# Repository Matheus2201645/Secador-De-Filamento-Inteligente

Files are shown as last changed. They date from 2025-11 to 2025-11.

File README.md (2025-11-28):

Desenvolvido por Matheus Milani, Thiago moraes, Kassem hamdoun, Vinicius Rodriges
Alunos instituto maua de tecnologia
Projeto ECA407 e ECA409

  Funcionalidades

Leitura de temperatura e umidade (SHT31)

Leitura de peso via HX711 + célula de carga

Controle automático:

Aquecedor (GPIO22)

Ventoinha (GPIO20)

Comunicação via USB Serial

Dashboard em PySide6 para monitoramento em tempo real

  Arquivos do Projeto

SecadoraInteligenteFinal.c – Firmware do Pico (leitura dos sensores, controle e envio serial)

Ui.py – Dashboard PySide6

CMakeLists.txt – Configuração do projeto

   Instalar Dashboard
pip install pyserial PySide6
python Ui.py

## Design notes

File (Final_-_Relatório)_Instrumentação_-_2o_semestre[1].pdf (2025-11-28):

SECADOR INTELIGENTE DE FILAMENTOS PARA IMPRESSÃO 3D

Matheus Milani 1

; Thiago Moraes 1

; Kassem Hamdoun 1

; Vinicius Rodrigues 1

1 Aluno do Instituto Mauá de Tecnologia (IMT).

Resumo. Este relatório apresenta o desenvolvimento de um secador inteligente de filamentos para impressão 3D, capaz de realizar simultaneamente o controle térmico para remoção de umidade e a medição precisa do peso do filamento restante. O sistema integra sensores, atuadores, uma placa controladora personalizada e um servidor web embarcado no Raspberry Pi Pico 2W, permitindo monitoramento e acionamento remoto do dispositivo. A solução proposta visa reduzir desperdícios, evitar falhas de impressão e melhorar a qualidade das peças produzidas em impressoras 3D do tipo FDM.

Introdução

A impressão 3D tornou-se uma tecnologia amplamente utilizada em processos educacionais, industriais e de prototipagem. Contudo, um dos maiores problemas enfrentados por usuários de impressoras do tipo FDM é a umidade acumulada nos filamentos termoplásticos, que compromete a qualidade das peças, causando bolhas, fissuras e superfícies irregulares.
Outro desafio recorrente é a ausência de informações precisas sobre a quantidade de filamento restante no carretel, o que pode resultar em interrupções inesperadas durante o processo de impressão, gerando desperdício de tempo, energia e material.
Diante desse cenário, este projeto propõe o desenvolvimento de um secador inteligente de filamentos com medição integrada de peso e controle remoto via servidor HTTP, oferecendo uma solução prática e eficaz para usuários de impressão 3D.
O presente projeto tem como objetivo desenvolver um dispositivo capaz de:
-) Secar filamentos de impressão 3D por meio de controle térmico;
-) Medir, em tempo real, o peso do filamento restante no carretel;
-) Disponibilizar uma interface web acessível via Wi-Fi, permitindo monitoramento e acionamento remoto do sistema;
-) Reduzir desperdícios e falhas decorrentes da umidade ou falta de filamento;
-) Unificar automação, eletrônica e software em uma solução compacta e acessível.

Material e Métodos

Materiais utilizados:

Os materiais utilizados no projeto foram: -) Raspberry Pi Pico 2W;
-) Módulo HX711;
-) Load Cell;
-) Sensor de temperatura SHT31;
-) Lâmpada aquecedora de réptil (100 W); -) Relé de estado sólido;
-) Coolers 5V (2 unidades);
-) Transistores BC547 (3 unidades);
-) Resistores de 1 kΩ (3 unidades);
-) Fonte de alimentação 5 V;
-) PCB personalizada (placa de circuito); -) Estrutura física impressa em 3D;
-) Conector C14.

Fundamentação teórica

Quanto à impressão 3D e efeitos da umidade, filamentos termoplásticos como PLA, ABS, PETG e Nylon são higroscópicos, absorvendo umidade naturalmente. Quando aquecidos no bico da impressora, o vapor de água interno gera estalos, bolhas e inconsistências estruturais.
Por isso, técnicas de secagem são essenciais para restaurar características ideais de impressão.
A load cell é um sensor baseado em extensômetros que converte força em deformação mecânica, permitindo medir massa. O módulo HX711 realiza a amplificação e conversão analógica-digital do sinal, possibilitando leitura precisa pelo microcontrolador.
O controle da temperatura é realizado por meio de um sensor digital (SHT31), que monitora o ambiente interno do secador e fornece dados para os atuadores (aquecedor e ventilação).
O Pico 2W possui conectividade Wi-Fi integrada, permitindo a criação de servidores web. Isso possibilita monitorar variáveis do sistema e enviar comandos para atuadores via navegador.

Descrição do projeto

O presente projeto consiste no desenvolvimento de um secador inteligente de filamentos para impressoras 3D, cuja finalidade é remover a umidade acumulada no material e fornecer ao usuário informações em tempo real sobre o peso restante do filamento. O sistema integra eletrônica, automação, controle térmico e interface web em um dispositivo compacto e eficiente.
O projeto é estruturado em três módulos principais:

Módulo Eletrônico de Controle:

O módulo eletrônico é composto por uma placa de circuito impresso (PCB) desenvolvida especificamente para o projeto, na qual estão integrados o microcontrolador Raspberry Pi Pico 2W, o módulo amplificador HX711, transistores, resistores de proteção e conexões para o relé de estado sólido e ventiladores.
Esse módulo realiza:
-) a leitura do sinal da célula de carga;
-) o monitoramento da temperatura interna através do sensor SHT31;
-) o acionamento dos atuadores (coolers e aquecedor);
-) a disponibilização dos dados coletados em uma interface web via Wi‑Fi.

Módulo Térmico e de Circulação de Ar:

A secagem do filamento ocorre por meio de uma lâmpada aquecedora de 100 W, acionada por um relé de estado sólido (SSR), que garante comutação rápida e segura.
A circulação de ar quente é realizada por dois coolers de 5 V, responsáveis por distribuir uniformemente o calor dentro da câmara de secagem.
O sensor SHT31, instalado próximo ao fluxo de ar, monitora continuamente a temperatura, garantindo segurança térmica e eficiência no processo.

Estrutura Mecânica:

A estrutura externa e os suportes internos foram projetados em ambiente CAD e produzidos por impressão 3D. A carcaça acomoda o rolo de filamento, a célula de carga e todos os módulos eletrônicos, além de fornecer:
-) estabilidade mecânica;
-) isolamento térmico adequado;

-) compartimentação dos elementos funcionais; -) facilidade de montagem e manutenção.
-) O conjunto permite ao usuário:
-) secar filamentos de maneira controlada;
-) monitorar temperatura e peso pelo navegador;
-) reduzir falhas de impressão relacionadas à umidade;
-) prevenir interrupções inesperadas devido à falta de material.

Metodologia

A construção do secador inteligente foi realizada em etapas simples e organizadas, passando pelo planejamento da arquitetura, montagem eletrônica, desenvolvimento da estrutura mecânica e integração final.

Arquitetura Geral do Sistema:

Primeiro, definimos como cada parte do projeto deveria se comunicar — sensores, atuadores e o Raspberry Pi Pico 2W. Para facilitar a visualização, elaboramos um diagrama de blocos, como mostrado na Figura 1.

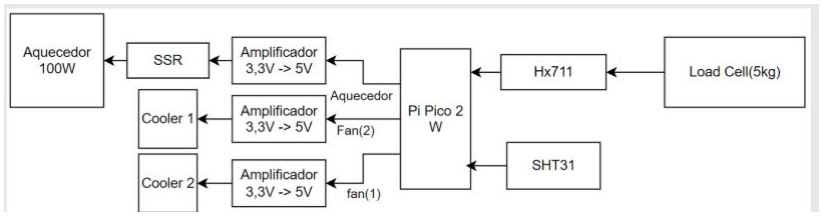
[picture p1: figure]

Figura 1 – Diagrama de blocos do projeto. Fonte: Autoria própria (2025).

Alimentação do Sistema:

Escolhemos uma fonte chaveada de 5 V para alimentar todos os componentes, como mostrado na Figura 2. Ela garante estabilidade e segurança durante o funcionamento.

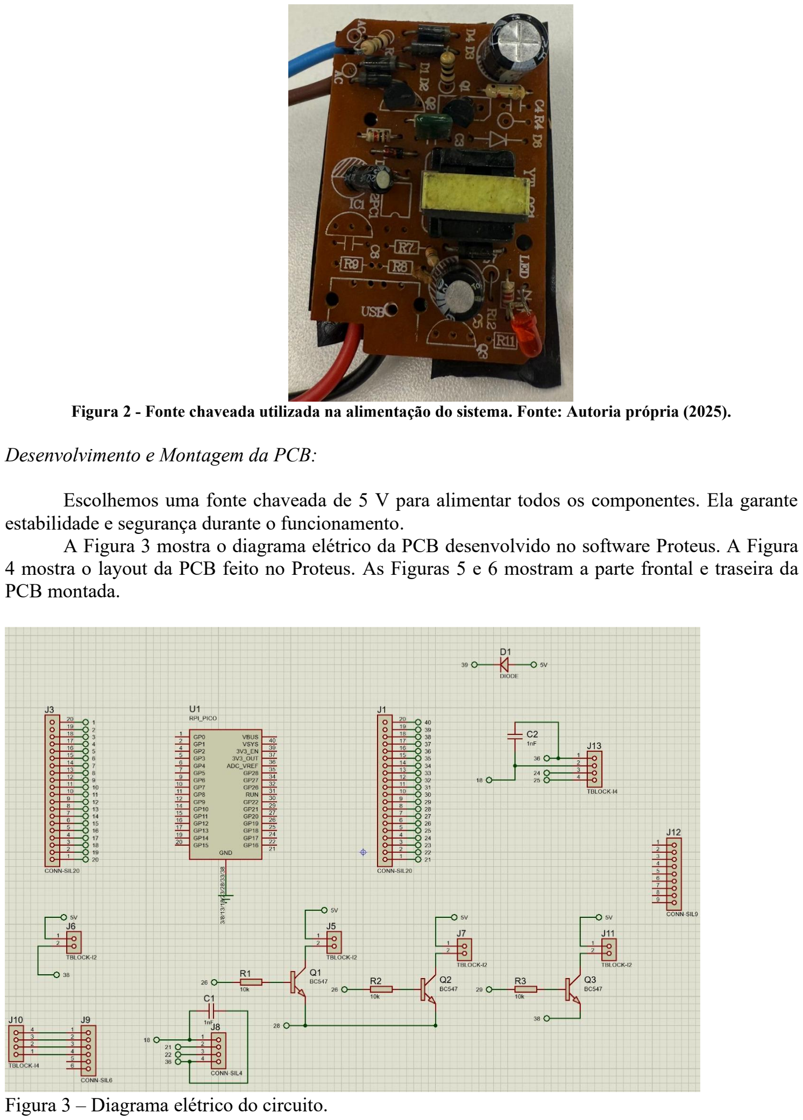
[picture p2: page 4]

Figura 2 - Fonte chaveada utilizada na alimentação do sistema. Fonte: Autoria própria (2025).

Desenvolvimento e Montagem da PCB:

Escolhemos uma fonte chaveada de 5 V para alimentar todos os componentes. Ela garante estabilidade e segurança durante o funcionamento.
A Figura 3 mostra o diagrama elétrico da PCB desenvolvido no software Proteus. A Figura 4 mostra o layout da PCB feito no Proteus. As Figuras 5 e 6 mostram a parte frontal e traseira da PCB montada.

Figura 3 – Diagrama elétrico do circuito.

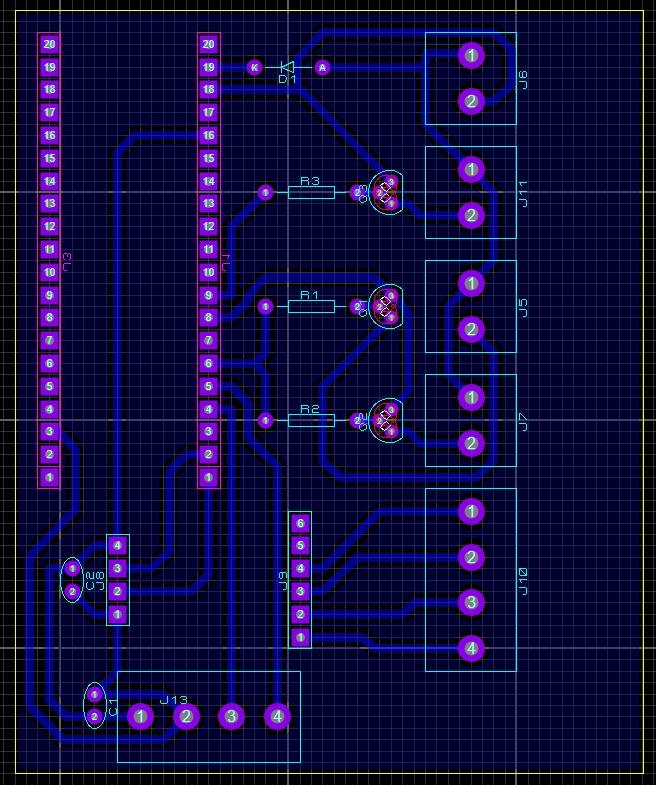
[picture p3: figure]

Figura 4 – Layout da PCB desenvolvido no Proteus.

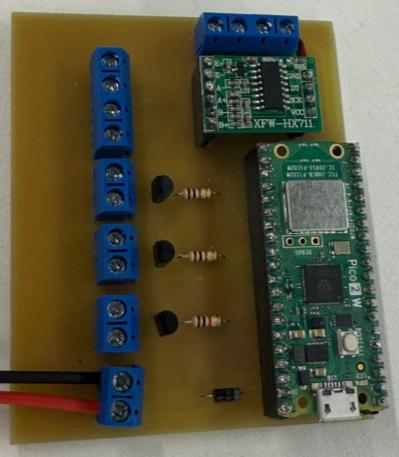
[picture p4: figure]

Figura 5 – Vista superior da PCB com Pico 2W, HX711 e transistores.

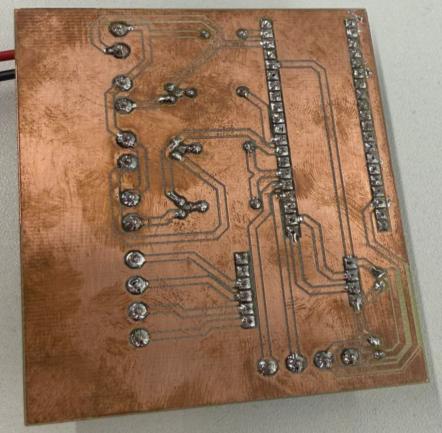
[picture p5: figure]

Figura 6 - Trilhamento inferior da PCB, mostrando conexões e soldagem.

Montagem Interna do Equipamento:

Com a placa pronta, passamos a integrar todos os componentes dentro da estrutura impressa em 3D, posicionando aquecedor, coolers e cabeamento. As Figuras 5 e 6 mostram a montagem do equipamento.

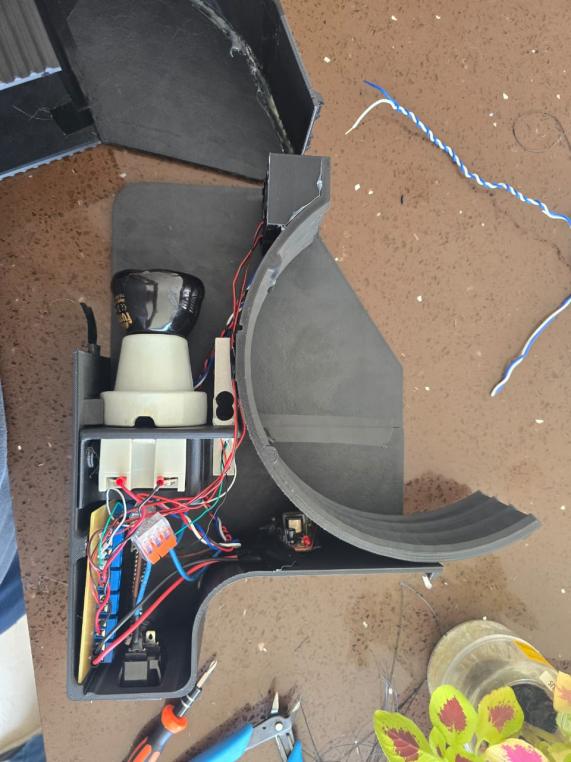
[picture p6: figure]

Figura 7 - Montagem interna com aquecedor, coolers e fiações.

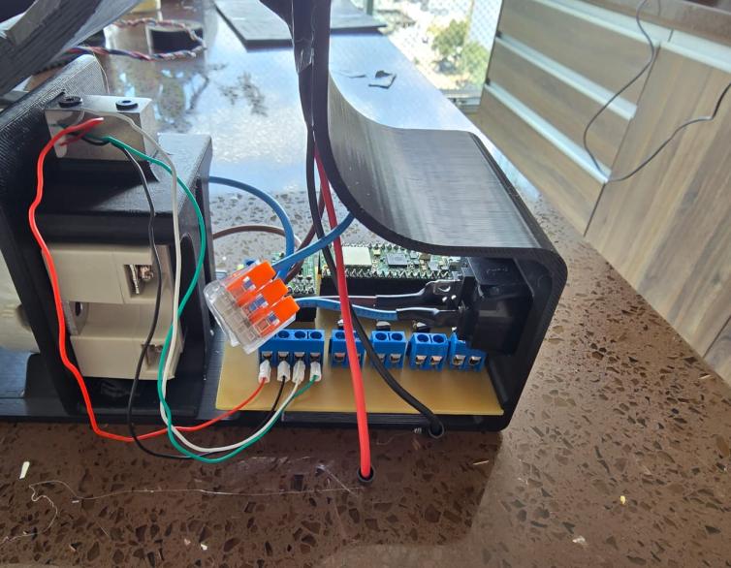
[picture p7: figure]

Figura 8 - PCB instalada no compartilhamento da estrutura.

Estrutura Mecânica Impressa em 3D.:

A estrutura foi modelada em CAD (Figura 7 e 8) e impressa em 3D, garantindo encaixe adequado dos componentes e boa circulação de ar.

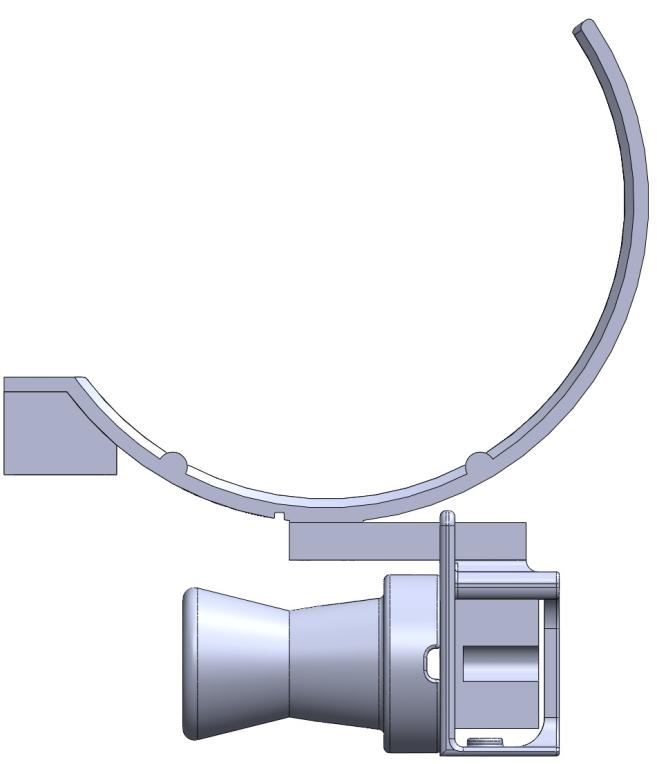
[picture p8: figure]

Figura 9 - Vista lateral do modelo 3D da estrutura.

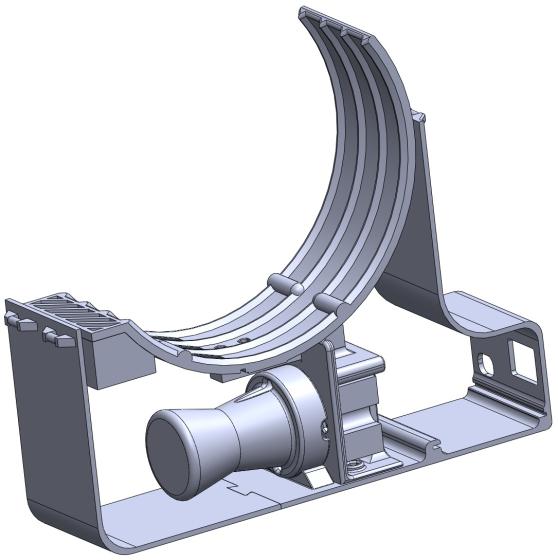
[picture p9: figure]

Figura 10 - Vista isométrica do modelo 3D.

Software do Sistema (Firmware e Interface de Monitoramento)

O software desenvolvido para o projeto é composto por duas partes principais:
(1) o firmware embarcado no Raspberry Pi Pico 2W, responsável pela leitura dos sensores e controle dos atuadores; e
(2) uma interface gráfica de monitoramento, criada em Python com PySide6, que permite visualizar em tempo real os dados transmitidos pela porta serial.

Firmware embarcado:

O firmware implementado no Raspberry Pi Pico 2W realiza a leitura dos sensores de temperatura/umidade (SHT31) e peso (HX711), além do controle automático do aquecedor e da ventoinha presentes no sistema de secagem de filamentos.

Na etapa de inicialização, o programa configura os pinos GPIO utilizados pelo HX711, pelo SHT31 (via I²C), pelo relé de estado sólido responsável pelo acionamento do aquecedor e pela ventoinha. O firmware também inicializa a comunicação I²C e executa um processo de tara da balança, realizando diversas leituras consecutivas do módulo HX711 e armazenando a média dessas leituras como ZERO_OFFSET, o que garante que o valor medido posteriormente corresponda apenas ao filamento e ao carretel.
Durante a execução contínua do laço principal, o firmware realiza periodicamente a leitura da temperatura e da umidade pelo SHT31 e obtém o peso calibrado a partir da célula de carga, utilizando o fator CALIBRATION_FACTOR. Em seguida, aplica uma lógica de controle baseada em histerese: quando a temperatura fica abaixo de 80 °C, o aquecedor é ativado; acima de 85 °C, é desativado. Caso o sistema ultrapasse o limite de segurança de 95 °C, o aquecedor é imediatamente desligado, e uma mensagem de alerta é exibida no console.
A ventoinha é acionada automaticamente sempre que a temperatura ultrapassa 35 °C ou enquanto o aquecedor estiver ligado, garantindo circulação do ar quente no interior da câmara. Ao final de cada ciclo, o firmware registra no terminal, via porta serial, os valores de temperatura, umidade, peso e estado do aquecedor, possibilitando o monitoramento em tempo real.

Interface gráfica de monitoramento (PySide6):

Para complementar o funcionamento do firmware, foi desenvolvida uma interface gráfica utilizando Python e PySide6, permitindo que os dados enviados pelo Raspberry Pi Pico 2W sejam exibidos de forma visual, organizada e acessível. A interface se conecta à porta serial selecionada pelo usuário e interpreta, linha a linha, as mensagens transmitidas pelo firmware.

Cada linha contém informações no formato:

T: xx.x C | H: xx.x % | Peso: xxxx | Aquecedor: ON/OFF

A aplicação processa esses dados e atualiza automaticamente um dashboard composto por quatro indicadores principais:
-) Temperatura (°C): exibida em destaque em um painel laranja;
-) Umidade (%): mostrada em painel azul;
-) Peso (g): exibido em painel verde;
-) Estado do aquecedor: mostrado em painel vermelho, indicando se está ON ou OFF.

Abaixo dos indicadores, a interface apresenta também um log serial contínuo, permitindo visualizar todas as mensagens recebidas do firmware em ordem cronológica. Essa interface auxilia durante testes e validações, fornecendo acompanhamento visual do comportamento térmico, da variação do peso do filamento e do acionamento dos atuadores durante o processo de secagem.
A interface gráfica é mostrada na Figura 9.

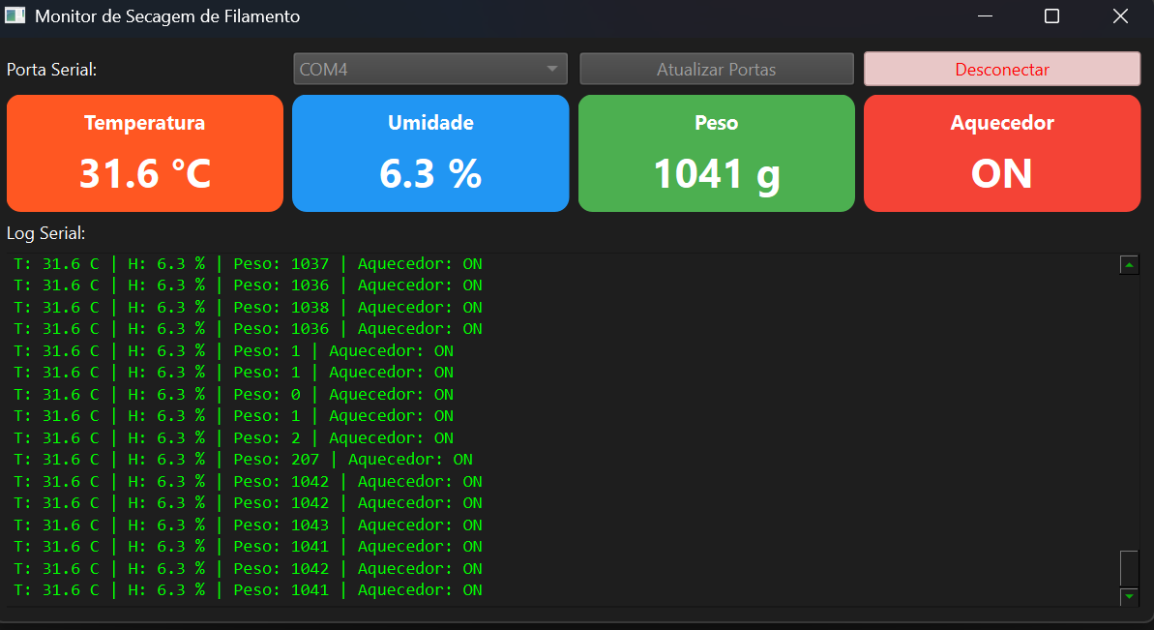
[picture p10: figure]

Figura 11 - Interface gráfica.

Resultados e Discussão

O desenvolvimento do projeto apresentou resultados funcionais, embora algumas limitações tenham sido encontradas ao longo do processo. A principal delas foi a impossibilidade de integrar a parte web ao Raspberry Pi Pico 2W. Diante disso, o grupo optou por simplificar a solução e utilizar a comunicação serial, criando uma interface em Python para permitir que o usuário acompanhasse o funcionamento do sistema diretamente pelo computador. Essa abordagem mostrou‑se viável e prática dentro do tempo disponível.
Durante os testes, verificou‑se que o sistema é capaz de atingir temperaturas elevadas, alcançando aproximadamente 80 °C em cerca de 40 minutos. Esse desempenho indica que o equipamento possui potencial para secar adequadamente diversos tipos de filamento, inclusive materiais mais sensíveis à umidade.
A célula de carga apresentou resultados satisfatórios, com medições consistentes e variação aproximada de ±5 g, o que é adequado para monitorar o consumo de filamento durante o processo de impressão 3D. Da mesma forma, a interface gráfica desenvolvida se mostrou bastante eficiente, exibindo de forma clara informações de temperatura, umidade, peso e estado do aquecedor, facilitando o acompanhamento em tempo real.
Mesmo com as limitações encontradas — tanto na integração Wi‑Fi quanto na necessidade de simplificar algumas etapas — o sistema funcionou de forma estável e cumpriu seus objetivos principais. Assim, consideramos que o projeto foi um sucesso dentro da proposta apresentada, entregando uma solução funcional, simples e efetiva.

Conclusões

O secador inteligente de filamentos apresenta uma solução prática e eficiente para problemas comuns na impressão 3D. A integração entre hardware, software embarcado e interface web demonstra o potencial da automação aplicada a dispositivos cotidianos. O projeto cumpre os objetivos propostos e pode ser ampliado futuramente com controle PID, armazenamento de dados em nuvem e otimização estrutural.

Referências Bibliográficas

IDRYER-UNIT. Disponível em: https://github.com/pavluchenkor/iDryer-Unit. Acesso em: 15 out. 2025.
AVIA SEMICONDUCTOR. 24-Bit Analog-to-Digital Converter (ADC) for Weigh Scales.
Disponível | em: | https://cdn.sparkfun.com/datasheets/Sensors/ForceFlex/hx711_english.pdf.
Acesso em: 25 out. 2025.
SENSIRION. Datasheet | SHT3x-DIS. | Disponível | em:
https://sensirion.com/media/documents/213E6A3B/63A5A569/Datasheet_SHT3x_DIS.pdf. Acesso em: 26 out. 2025.
RASPBERRY | PI | FOUNDATION. Pico-series | Microcontrollers. | Disponível | em:
https://www.raspberrypi.com/documentation/microcontrollers/pico-series.html. Acesso em: 10 out. 2025.

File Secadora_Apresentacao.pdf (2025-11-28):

# Secadora de Filamento Inteligente

# Instrumentação + Microcontroladores

Vinícius G. Rodrigues - 22.01711-9

Matheus Milani - 22.01645-7 | Thiago C. S. Moraes - 22.01303-2

Kassem Mahmoud Hamdoun - 22.00380-0

# Introdução

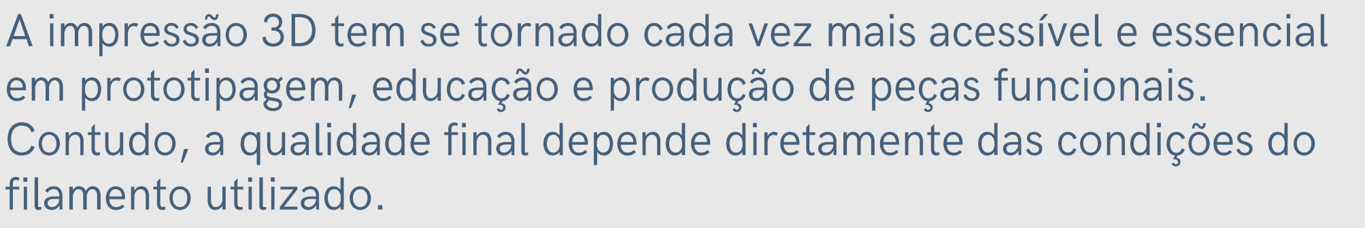
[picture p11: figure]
filamento utilizado.

- A impressão 3D tem se tornado cada vez mais acessível e essencial em prototipagem, educação e produção de peças funcionais. Contudo, a qualidade final depende diretamente das condições do

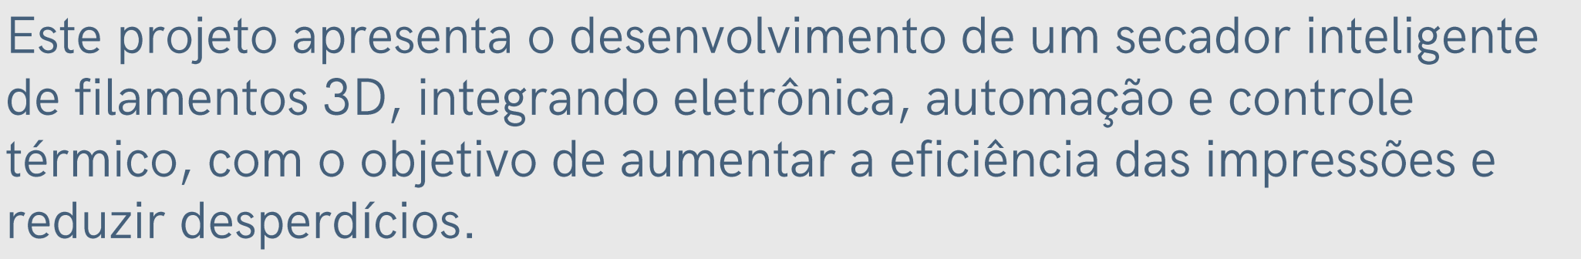
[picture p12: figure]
reduzir desperdícios.

- Este projeto apresenta o desenvolvimento de um secador inteligente de filamentos 3D, integrando eletrônica, automação e controle térmico, com o objetivo de aumentar a eficiência das impressões e

01

01.1

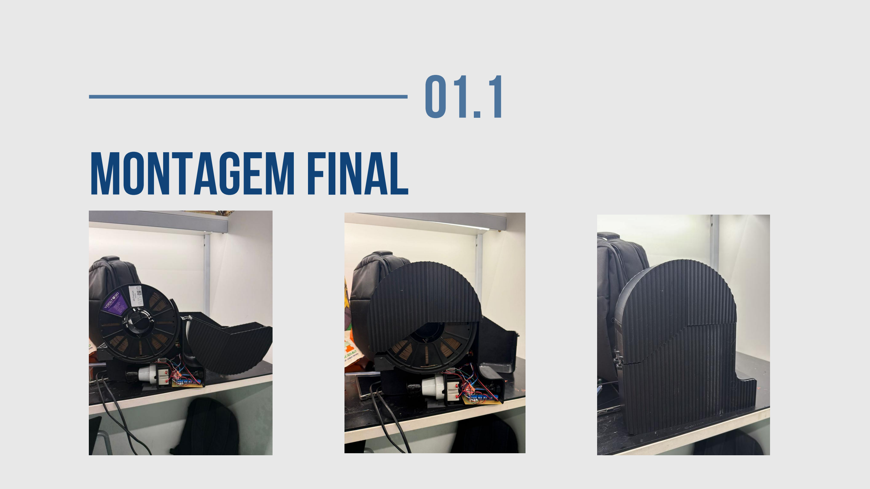
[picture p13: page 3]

# Montagem final

# Objetivo do projeto

- Desenvolver um dispositivo capaz de secar filamentos de impressão 3D, removendo umidade excessiva.

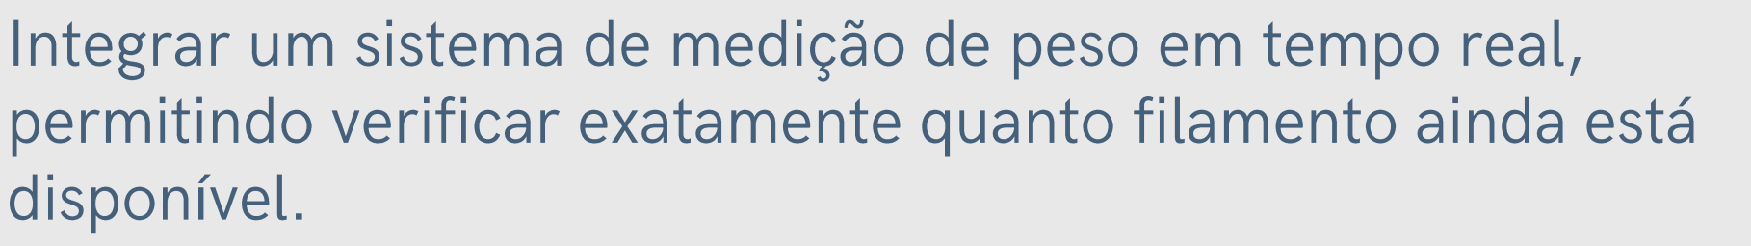
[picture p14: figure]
disponível.

- Integrar um sistema de medição de peso em tempo real, permitindo verificar exatamente quanto filamento ainda está

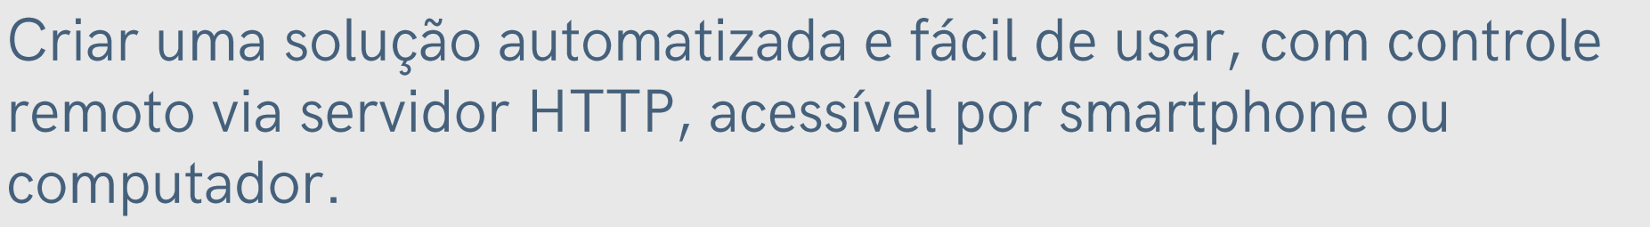
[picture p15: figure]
computador.

- Criar uma solução automatizada e fácil de usar, com controle remoto via servidor HTTP, acessível por smartphone ou
- Reduzir falhas de impressão, melhorar a qualidade final das

02

# Diagrama de blocos

03

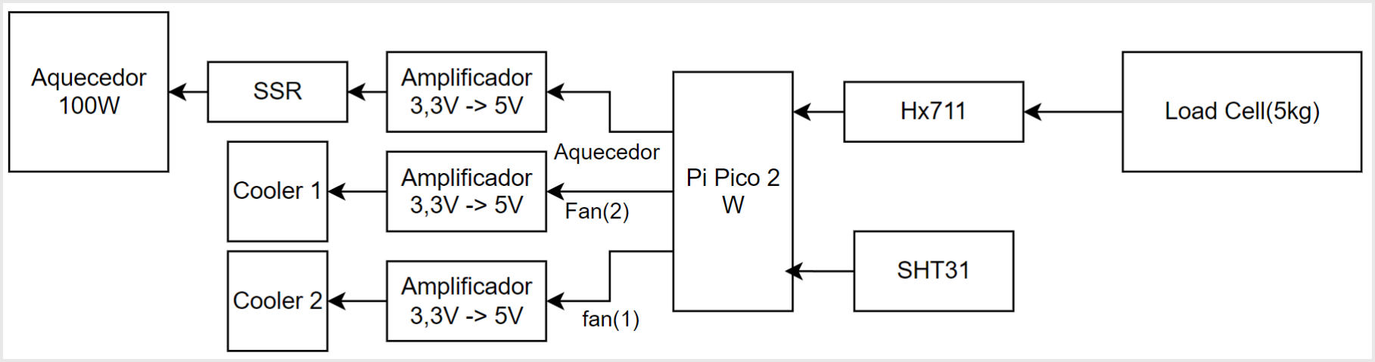
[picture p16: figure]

# Arquitetura do Sistema

03 | • Raspberry Pi Pico 2W como controlador principal
| • SHT31 para leitura de temperatura e umidade
- Load Cell + HX711 para medir o peso

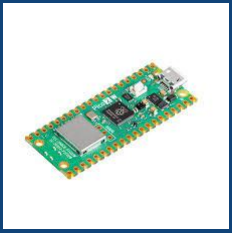
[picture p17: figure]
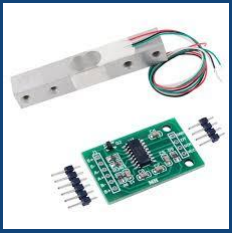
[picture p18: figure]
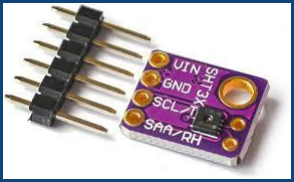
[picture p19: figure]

# Arquitetura do Sistema

03 | • Aquecedor (lâmpada de réptil 100W) com
- Coolers 5V controlados por transistores BC547
- Fonte chaveada convertendo AC → 5V DC

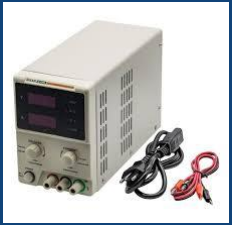
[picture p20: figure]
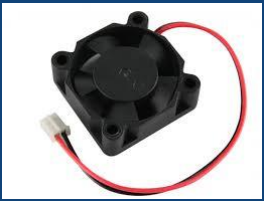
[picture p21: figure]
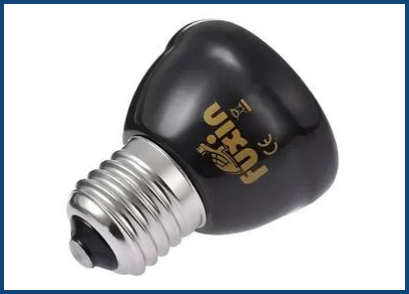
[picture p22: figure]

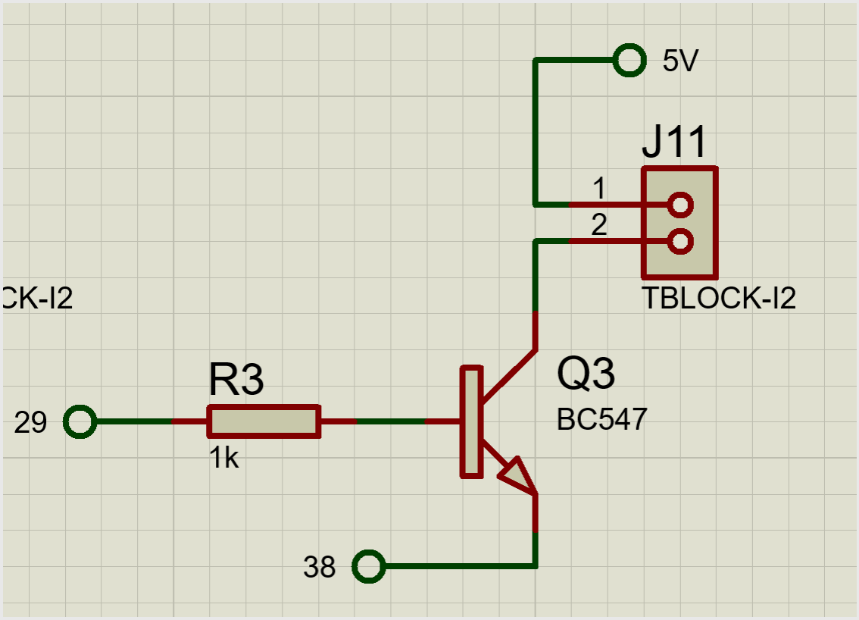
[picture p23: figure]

# Arquitetura do Sistema

03

04

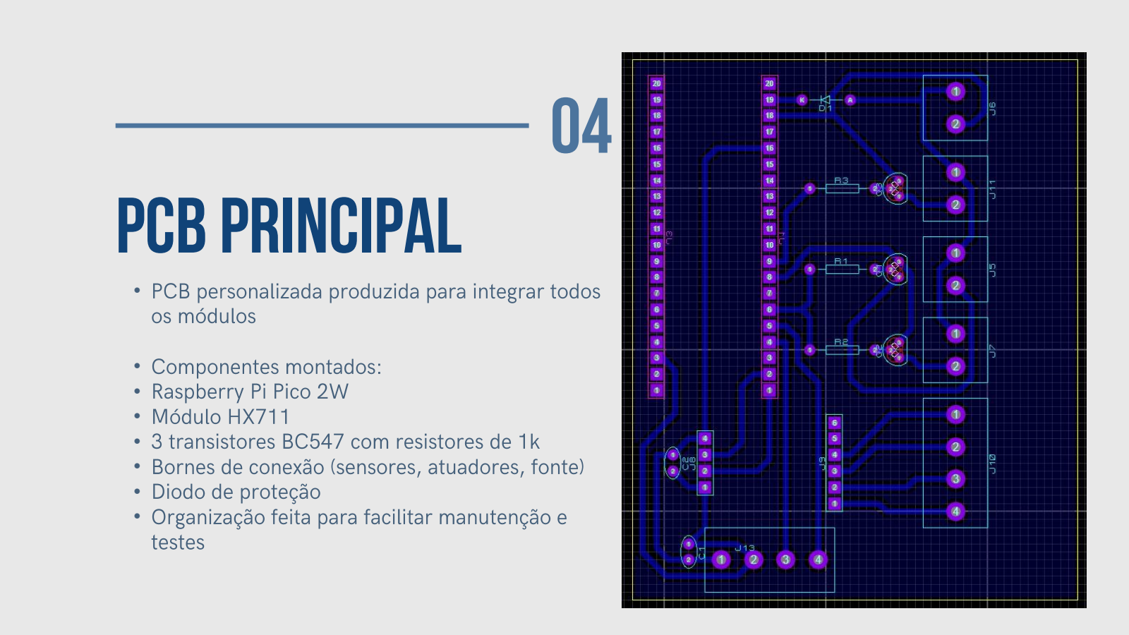
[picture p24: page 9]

# PCB Principal

- PCB personalizada produzida para integrar todos os módulos
- Componentes montados:
- Raspberry Pi Pico 2W
- Módulo HX711
- 3 transistores BC547 com resistores de 1k
- Bornes de conexão (sensores, atuadores, fonte)
- Diodo de proteção
- Organização feita para facilitar manutenção e testes

04


# PCB Principal

- PCB personalizada produzida para integrar todos os módulos
- Componentes montados:
- Raspberry Pi Pico 2W
- Módulo HX711
- 3 transistores BC547 com resistores de 1k
- Bornes de conexão (sensores, atuadores, fonte)
- Diodo de proteção
- Organização feita para facilitar manutenção e testes

# PCB (Frente / verso)

05


06


# Parte Mecânica (Suporte 3D)

- Suporte do carretel impresso em 3D
- Estrutura curvada para distribuição do peso
- Base encaixada diretamente na load cell
- Mantém o filamento estável durante secagem e pesagem
- Base para a lâmpada de aquecimento

# Funcionamento do Sistema

07

Passo 1
Usuário liga o
secador

Passo 2
Raspberry Pi Pico
inicia o web server
via Wi-Fi

Passo 3
Load cell mede peso
→ Pico desconta tara
do carretel

Passo 4
SHT31 monitora
temperatura

Passo 5
Coolers circulam ar
quente

Passo 6
Relé aciona a lâmpada
aquecedora

Passo 7
Usuário controla tudo via
navegador (HTTP):
- Ligar/desligar aquecimento
- Monitorar temperatura
- Ver peso restante do
filamento

# Funcionamento do Sistema 07


# Benefícios do Projeto

Melhora a qualidade das impressões

Redução de
desperdício

01

Evita falhas por falta de filamento
Automação e controle remoto

02

03

04

08

# Calibração11


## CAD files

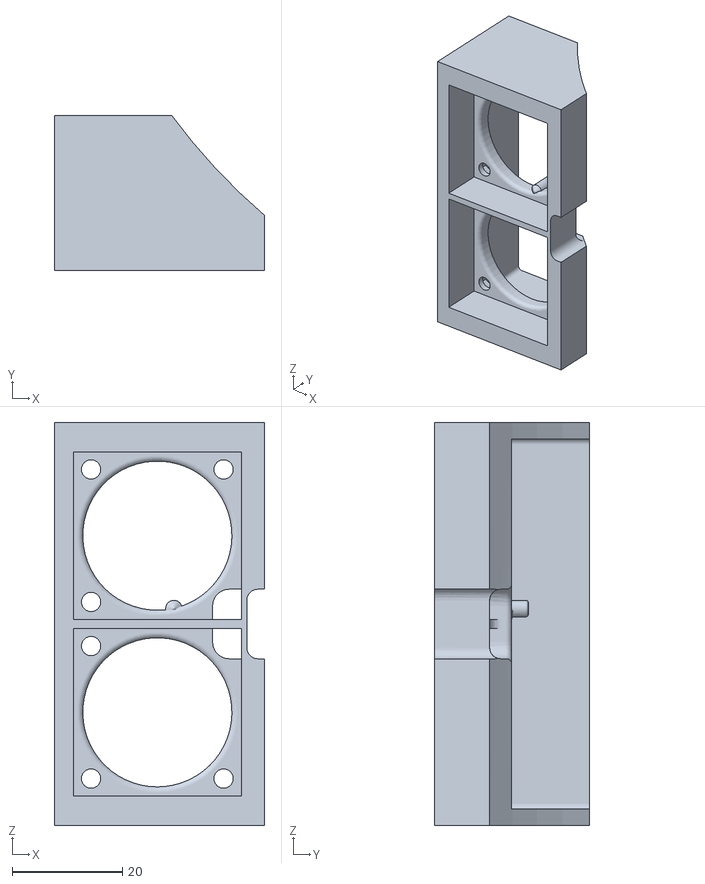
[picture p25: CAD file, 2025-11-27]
STLs/SuporteFan.STL
38.1 x 28.1 x 73.0

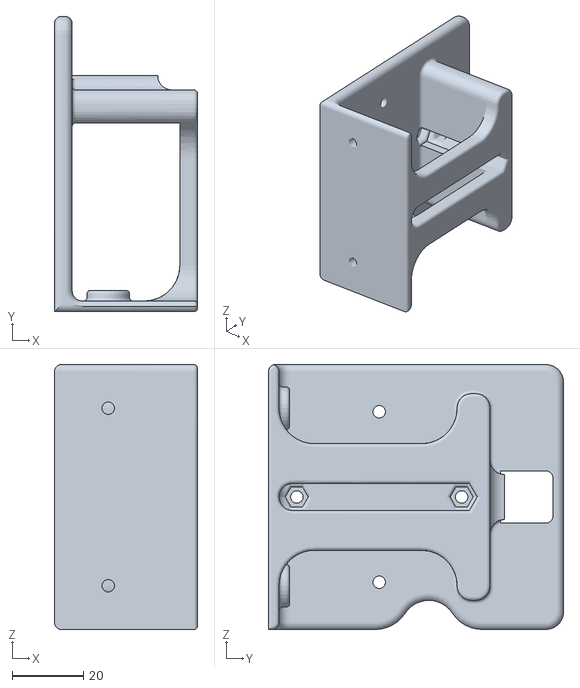
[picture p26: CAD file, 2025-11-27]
STLs/SuporteBase.STL
40.3 x 83.1 x 74.6

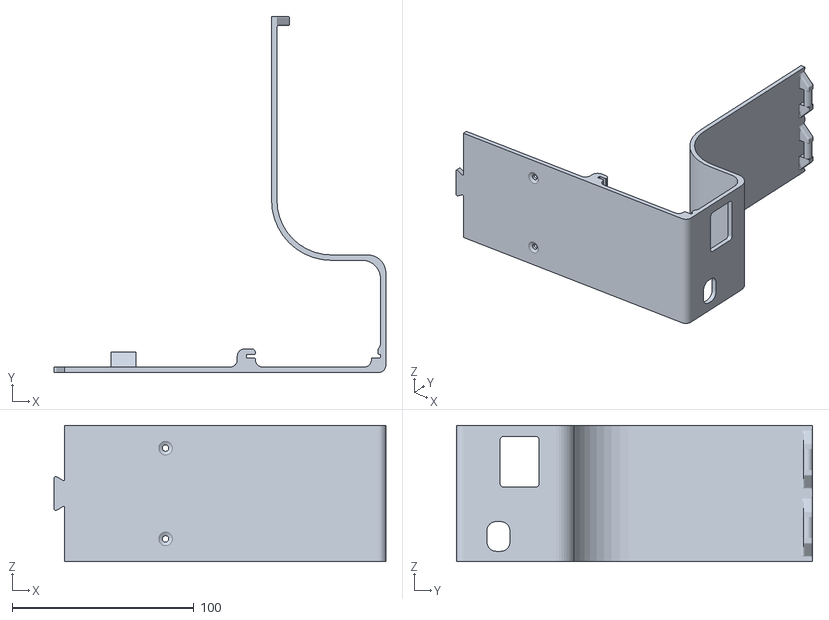
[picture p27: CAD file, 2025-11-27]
STLs/meioTraseira.STL
182.8 x 196.1 x 75.0

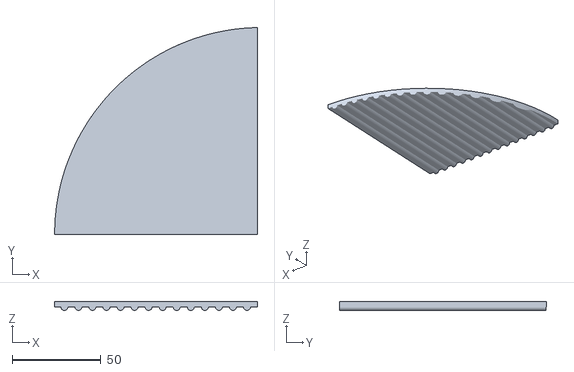
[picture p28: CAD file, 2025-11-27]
STLs/LateralTampa2.STL
114.6 x 116.8 x 4.99

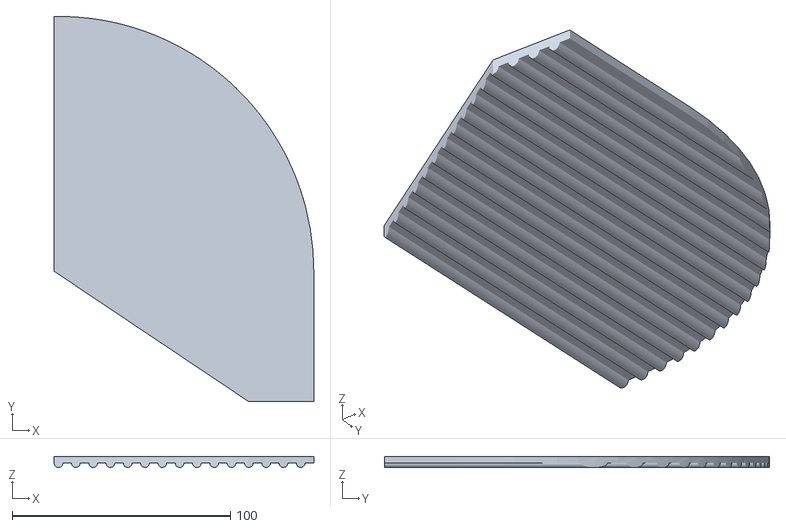
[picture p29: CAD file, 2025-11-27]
STLs/LateralTampa1.STL
119.0 x 176.5 x 5.00

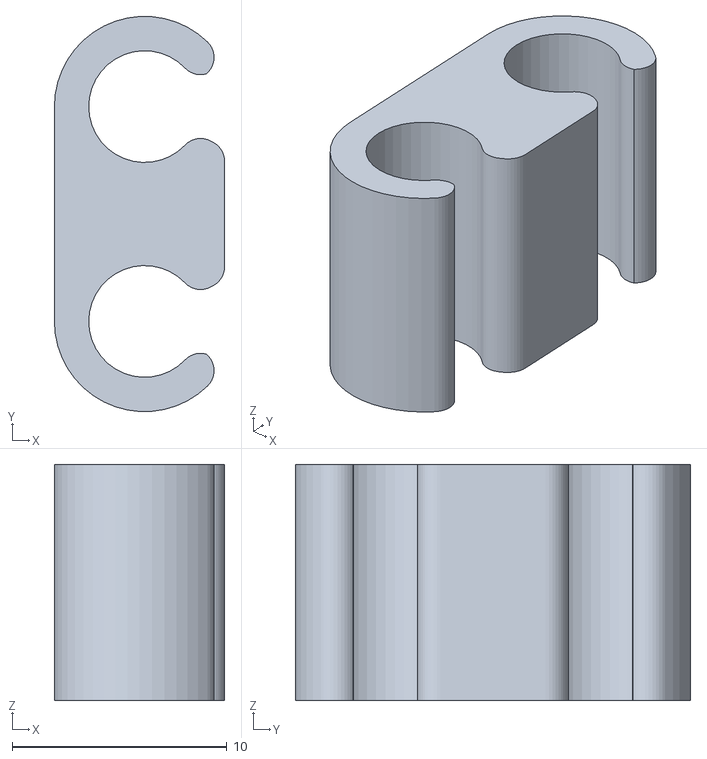
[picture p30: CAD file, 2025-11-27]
STLs/dobradica.STL
7.93 x 18.4 x 11.0

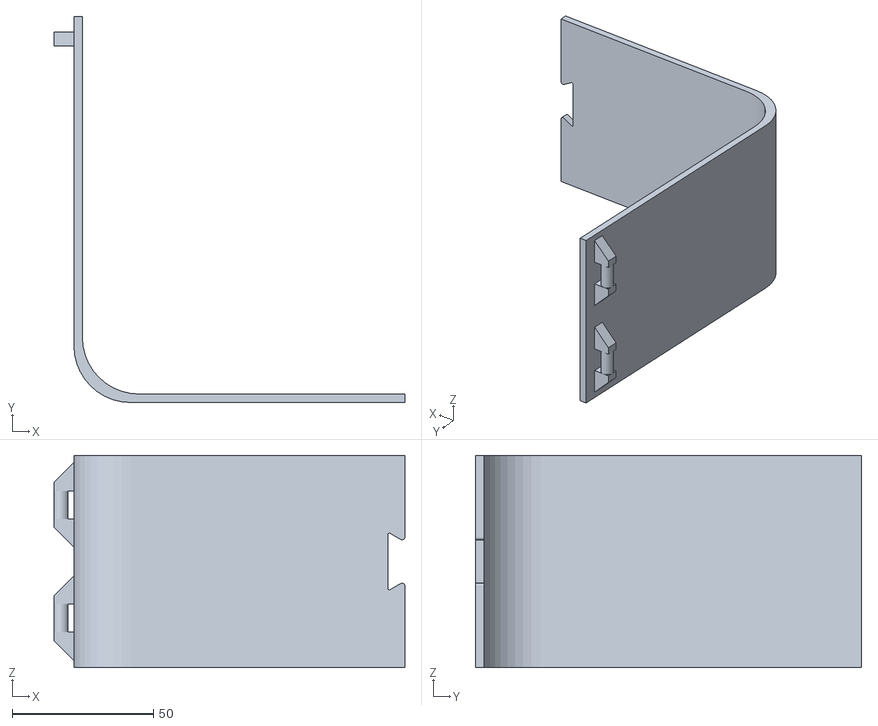
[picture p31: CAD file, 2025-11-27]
STLs/MeioFrente.STL
124.0 x 136.4 x 75.0

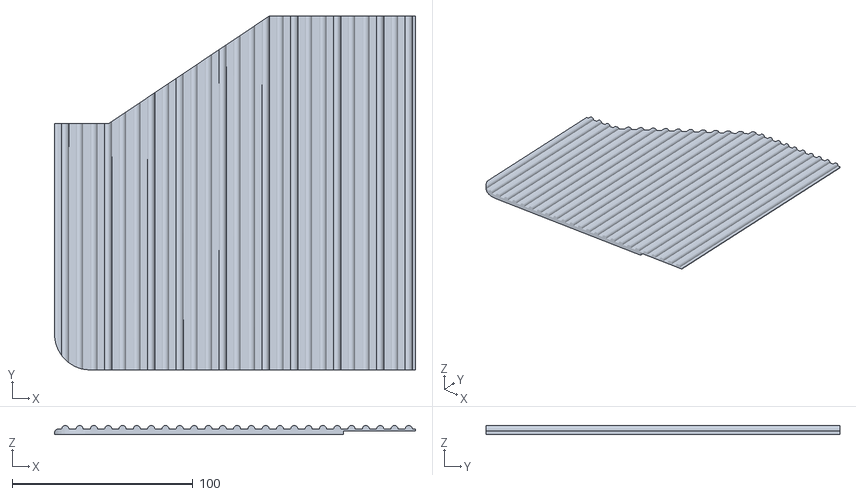
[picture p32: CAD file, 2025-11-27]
STLs/LateralInferior2.STL
200.0 x 196.1 x 5.00

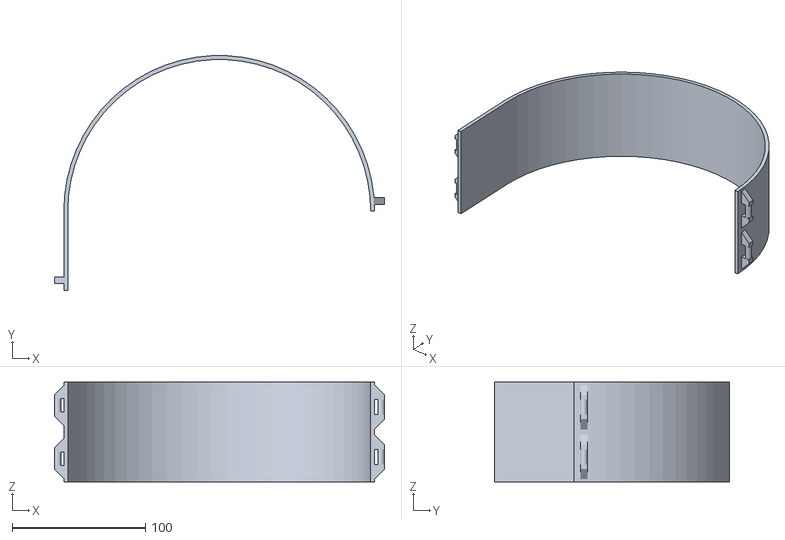
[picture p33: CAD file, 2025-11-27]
STLs/meioTampa.STL
248.0 x 176.3 x 75.0

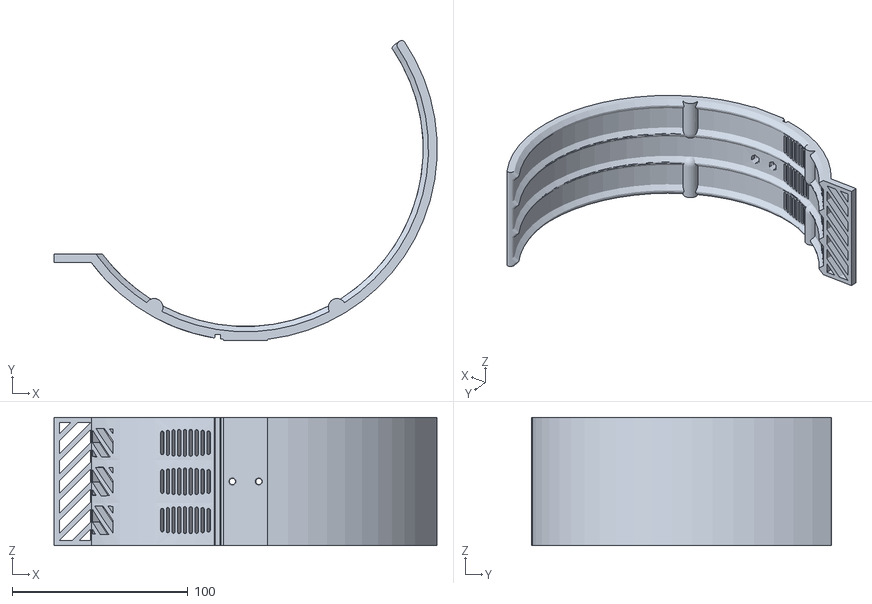
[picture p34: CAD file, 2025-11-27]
STLs/SuporteFilamento.STL
217.8 x 170.7 x 73.0

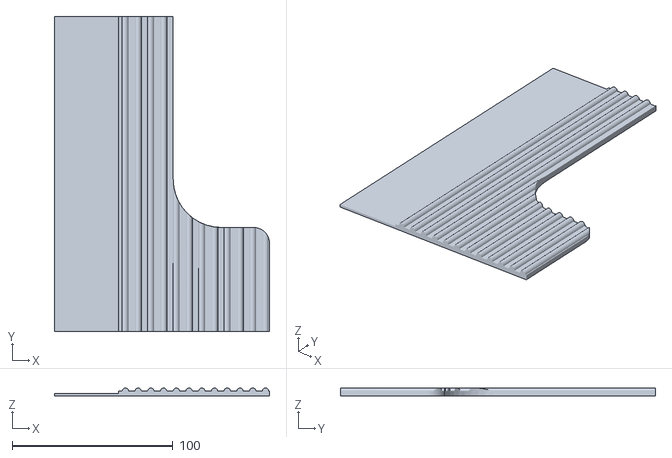
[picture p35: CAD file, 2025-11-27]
STLs/LateralInferior1.STL
134.0 x 196.1 x 4.99

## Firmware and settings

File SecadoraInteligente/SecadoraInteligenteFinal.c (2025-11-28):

/**
 * Secadora Filamento para Raspberry Pi Pico 2 W
 * * Hardware:
 * - Load Cell (HX711): DT=GP16, SCK=GP17
 * - SHT31 (Temp/Hum): SDA=GP18, SCL=GP19 (I2C1)
 * - Fan (Ventoinha): GP20
 * - Heater (SSR): GP22
 */

#include <stdio.h>
#include <stdint.h>
#include <stdbool.h>
#include "pico/stdlib.h"
#include "hardware/i2c.h"
#include "hardware/gpio.h"

// --- Definições de Pinos ---
#define HX711_DT_PIN  16
#define HX711_SCK_PIN 17
#define I2C_SDA_PIN   19
#define I2C_SCL_PIN   18
#define FAN_PIN       20
#define HEATER_PIN    22

// --- Configurações do I2C (SHT31) ---
#define I2C_PORT      i2c1
uint8_t SHT31_ADDR = 0x44; 

// --- Parâmetros de Controle ---
float TARGET_TEMP = 85.0;       
float TEMP_HYSTERESIS = 5.0;    
float MAX_SAFE_TEMP = 95.0;     

// Variáveis globais para calibração da balança
long ZERO_OFFSET = 0;
float CALIBRATION_FACTOR = 426.0; 



int32_t hx711_read_raw() {
    uint32_t count = 0;
    // Aguarda o chip estar pronto
    while (gpio_get(HX711_DT_PIN));
    
    // Leitura dos bits
    for (int i = 0; i < 24; i++) {
        gpio_put(HX711_SCK_PIN, 1);
        sleep_us(1);
        gpio_put(HX711_SCK_PIN, 0);
        sleep_us(1);
        count = count << 1;
        if (gpio_get(HX711_DT_PIN)) count++;
    }
    
    // Utilizei Ganho 128 para redução de ruido
    gpio_put(HX711_SCK_PIN, 1);
    sleep_us(1);
    gpio_put(HX711_SCK_PIN, 0);
    sleep_us(1);
    
    if (count & 0x800000) count |= 0xFF000000;
    return (int32_t)count;
}

float get_weight_units() {
    int32_t val = hx711_read_raw();
    return (float)(val - ZERO_OFFSET) / CALIBRATION_FACTOR;
}

bool sht31_read(float *temp, float *hum) {
    uint8_t cmd[2] = {0x24, 0x00}; 
    uint8_t buf[6];

    int ret = i2c_write_blocking(I2C_PORT, SHT31_ADDR, cmd, 2, false);
    if (ret == PICO_ERROR_GENERIC) return false;


    sleep_ms(20);


    ret = i2c_read_blocking(I2C_PORT, SHT31_ADDR, buf, 6, false);

    uint16_t raw_temp = (buf[0] << 8) | buf[1];
    *temp = -45.0f + (175.0f * (float)raw_temp / 65535.0f);
    uint16_t raw_hum = (buf[3] << 8) | buf[4];
    *hum = 100.0f * ((float)raw_hum / 65535.0f);
    return true;
}
void setup() {
    stdio_init_all();
    
    gpio_init(HEATER_PIN);
    gpio_set_dir(HEATER_PIN, GPIO_OUT);
    gpio_put(HEATER_PIN, 0);

    gpio_init(FAN_PIN);
    gpio_set_dir(FAN_PIN, GPIO_OUT);
    gpio_put(FAN_PIN, 0);

    gpio_init(HX711_DT_PIN);
    gpio_set_dir(HX711_DT_PIN, GPIO_IN);
    gpio_init(HX711_SCK_PIN);
    gpio_set_dir(HX711_SCK_PIN, GPIO_OUT);
    gpio_put(HX711_SCK_PIN, 0);

    i2c_init(I2C_PORT, 100 * 1000); // 100kHz
    gpio_set_function(I2C_SDA_PIN, GPIO_FUNC_I2C);
    gpio_set_function(I2C_SCL_PIN, GPIO_FUNC_I2C);
    
    gpio_pull_up(I2C_SDA_PIN);
    gpio_pull_up(I2C_SCL_PIN);

    sleep_ms(5000); 

    printf("\n=== Inicializando Sistema de Secagem ===\n");

    printf("Tarando balança (nao coloque peso agora)...\n");
    long soma = 0;
    for(int i=0; i<10; i++) {
        soma += hx711_read_raw();
        sleep_ms(50);
    }
    ZERO_OFFSET = soma / 10;
    printf("Tara definida em: %ld\n", ZERO_OFFSET);
}

int main() {
    setup();

    float current_temp = 0.0;
    float current_hum = 0.0;
    float weight = 0.0;
    bool heater_state = false;

    while (true) {
        bool sensor_ok = sht31_read(&current_temp, &current_hum);

        weight = get_weight_units();

        if (!sensor_ok) {
            
            gpio_put(HEATER_PIN, 0);
            heater_state = false;
            
            gpio_put(FAN_PIN, 1); 
            
            sleep_ms(2000);
        }
        if (current_temp >= MAX_SAFE_TEMP) {
            heater_state = false;
            printf("!!! PERIGO: Temperatura acima do limite de seguranca (%.1f C) !!!\n", current_temp);
        } 
        else {
            if (current_temp < (TARGET_TEMP - TEMP_HYSTERESIS)) {
                heater_state = true;
            } else if (current_temp > TARGET_TEMP) {
                heater_state = false;
            }
        }

        gpio_put(HEATER_PIN, heater_state);
        
        if (current_temp > 35.0 || heater_state) {
            gpio_put(FAN_PIN, 1);
        } else {
            gpio_put(FAN_PIN, 0);
        }

        printf("T: %.1f C | H: %.1f %% | Peso: %.0f | Aquecedor: %s\n", 
               current_temp, current_hum, weight, heater_state ? "ON" : "OFF");
        sleep_ms(1000);
    }
}

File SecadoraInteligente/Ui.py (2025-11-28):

import sys
import serial
import serial.tools.list_ports
import re
from PySide6.QtWidgets import (QApplication, QMainWindow, QWidget, QVBoxLayout, 
                               QHBoxLayout, QLabel, QPushButton, QComboBox, 
                               QTextEdit, QFrame, QGroupBox)
from PySide6.QtCore import QThread, Signal, Qt, Slot
from PySide6.QtGui import QFont, QColor

# --- Thread de Trabalho (Serial Worker) ---
class SerialWorker(QThread):
    # Sinais para comunicar com a interface principal
    data_received = Signal(str)
    error_occurred = Signal(str)
    
    def __init__(self, port_name, baud_rate=115200):
        super().__init__()
        self.port_name = port_name
        self.baud_rate = baud_rate
        self.is_running = True
        self.serial_port = None

    def run(self):
        try:
            self.serial_port = serial.Serial(self.port_name, self.baud_rate, timeout=1)
            print(f"Conectado a {self.port_name}")
            
            while self.is_running:
                if self.serial_port.in_waiting:
                    # Lê a linha, decodifica bytes para string e remove espaços extras
                    line = self.serial_port.readline().decode('utf-8', errors='ignore').strip()
                    if line:
                        self.data_received.emit(line)
        except Exception as e:
            self.error_occurred.emit(str(e))
        finally:
            if self.serial_port and self.serial_port.is_open:
                self.serial_port.close()

    def stop(self):
        self.is_running = False
        self.wait()

# --- Janela Principal ---
class MainWindow(QMainWindow):
    def __init__(self):
        super().__init__()
        self.setWindowTitle("Monitor de Secagem de Filamento")
        self.resize(800, 500)
        
        # Variável para a thread
        self.worker = None

        # Regex para capturar os dados do seu printf:
        # Padrão: "T: %.1f C | H: %.1f %% | Peso: %.0f | Aquecedor: %s"
        self.regex_pattern = re.compile(r"T:\s*([\d.]+)\s*C\s*\|\s*H:\s*([\d.]+)\s*%\s*\|\s*Peso:\s*([-\d.]+)\s*\|\s*Aquecedor:\s*(ON|OFF)")

        self.setup_ui()
        self.refresh_ports()

    def setup_ui(self):
        # Layout Principal
        central_widget = QWidget()
        self.setCentralWidget(central_widget)
        main_layout = QVBoxLayout(central_widget)

        # --- Área de Conexão ---
        conn_layout = QHBoxLayout()
        
        self.combo_ports = QComboBox()
        self.btn_refresh = QPushButton("Atualizar Portas")
        self.btn_refresh.clicked.connect(self.refresh_ports)
        
        self.btn_connect = QPushButton("Conectar")
        self.btn_connect.setCheckable(True) # Botão funciona como Toggle (Liga/Desliga)
        self.btn_connect.clicked.connect(self.toggle_connection)

        conn_layout.addWidget(QLabel("Porta Serial:"))
        conn_layout.addWidget(self.combo_ports)
        conn_layout.addWidget(self.btn_refresh)
        conn_layout.addWidget(self.btn_connect)
        
        main_layout.addLayout(conn_layout)

        # --- Dashboard (Displays) ---
        dash_layout = QHBoxLayout()

        # Widget Temperatura
        self.lbl_temp = self.create_card("Temperatura", "--- °C", "#FF5722") # Laranja
        dash_layout.addWidget(self.lbl_temp['frame'])

        # Widget Umidade
        self.lbl_hum = self.create_card("Umidade", "--- %", "#2196F3") # Azul
        dash_layout.addWidget(self.lbl_hum['frame'])

        # Widget Peso
        self.lbl_weight = self.create_card("Peso", "--- g", "#4CAF50") # Verde
        dash_layout.addWidget(self.lbl_weight['frame'])

        # Widget Aquecedor (Status)
        self.lbl_heater = self.create_card("Aquecedor", "OFF", "#9E9E9E") # Cinza
        dash_layout.addWidget(self.lbl_heater['frame'])

        main_layout.addLayout(dash_layout)

        # --- Log de Texto (Terminal) ---
        self.log_view = QTextEdit()
        self.log_view.setReadOnly(True)
        self.log_view.setStyleSheet("background-color: #1e1e1e; color: #00ff00; font-family: Consolas;")
        main_layout.addWidget(QLabel("Log Serial:"))
        main_layout.addWidget(self.log_view)

    def create_card(self, title, default_val, color_hex):
        """Cria um cartão visual para exibir dados"""
        frame = QFrame()
        frame.setFrameShape(QFrame.StyledPanel)
        frame.setStyleSheet(f"QFrame {{ background-color: {color_hex}; border-radius: 10px; }}")
        
        layout = QVBoxLayout(frame)
        
        lbl_title = QLabel(title)
        lbl_title.setStyleSheet("color: white; font-weight: bold; font-size: 14px;")
        lbl_title.setAlignment(Qt.AlignCenter)
        
        lbl_value = QLabel(default_val)
        lbl_value.setStyleSheet("color: white; font-weight: bold; font-size: 28px;")
        lbl_value.setAlignment(Qt.AlignCenter)
        
        layout.addWidget(lbl_title)
        layout.addWidget(lbl_value)
        
        return {'frame': frame, 'label': lbl_value}

    def refresh_ports(self):
        self.combo_ports.clear()
        ports = serial.tools.list_ports.comports()
        for port in ports:
            self.combo_ports.addItem(port.device)

    def toggle_connection(self):
        if self.btn_connect.isChecked():
            # Iniciar Conexão
            port = self.combo_ports.currentText()
            if not port:
                self.log_message("Selecione uma porta serial!")
                self.btn_connect.setChecked(False)
                return

            self.worker = SerialWorker(port)
            self.worker.data_received.connect(self.process_data)
            self.worker.error_occurred.connect(self.handle_error)
            self.worker.start()
            
            self.btn_connect.setText("Desconectar")
            self.btn_connect.setStyleSheet("background-color: #ffcccc; color: red;")
            self.combo_ports.setEnabled(False)
            self.btn_refresh.setEnabled(False)
            self.log_message(f"Conectando a {port}...")
        else:
            # Parar Conexão
            if self.worker:
                self.worker.stop()
                self.worker = None
            
            self.btn_connect.setText("Conectar")
            self.btn_connect.setStyleSheet("")
            self.combo_ports.setEnabled(True)
            self.btn_refresh.setEnabled(True)
            self.log_message("Desconectado.")

    @Slot(str)
    def process_data(self, line):
        # 1. Mostrar linha crua no log
        self.log_message(line)

        # 2. Tentar parsear a string formatada do seu C code
        # Formato esperado: T: 85.0 C | H: 20.0 % | Peso: 150 | Aquecedor: ON
        match = self.regex_pattern.search(line)
        
        if match:
            temp = match.group(1)
            hum = match.group(2)
            weight = match.group(3)
            heater = match.group(4)
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

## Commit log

2025-11-27 Arquivos STL
    [LateralInferior1.STL, LateralInferior2.STL, LateralTampa1.STL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]
2025-11-28 programação Pi pico e Ui
